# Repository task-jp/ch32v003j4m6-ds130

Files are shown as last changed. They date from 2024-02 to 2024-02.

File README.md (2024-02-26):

# Gathering CLOCK

Simple two LEDs clock that tells first 5mins in hours.

## Features
* pushing a button in 30 secs resets the clock

|Min|Green|Red|
|---|-----|---|
|0-5|On||
|5-10|Blink||
|10-55||On|
|55-60||Blink|

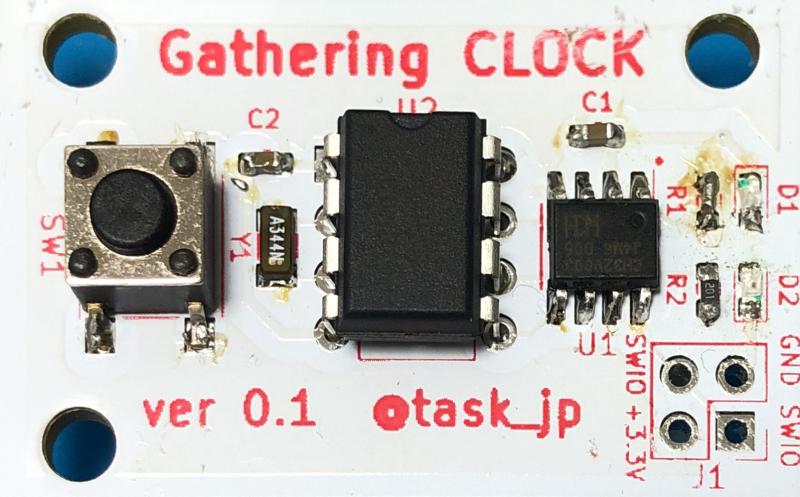
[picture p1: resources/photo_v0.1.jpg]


## Schematic and Layout

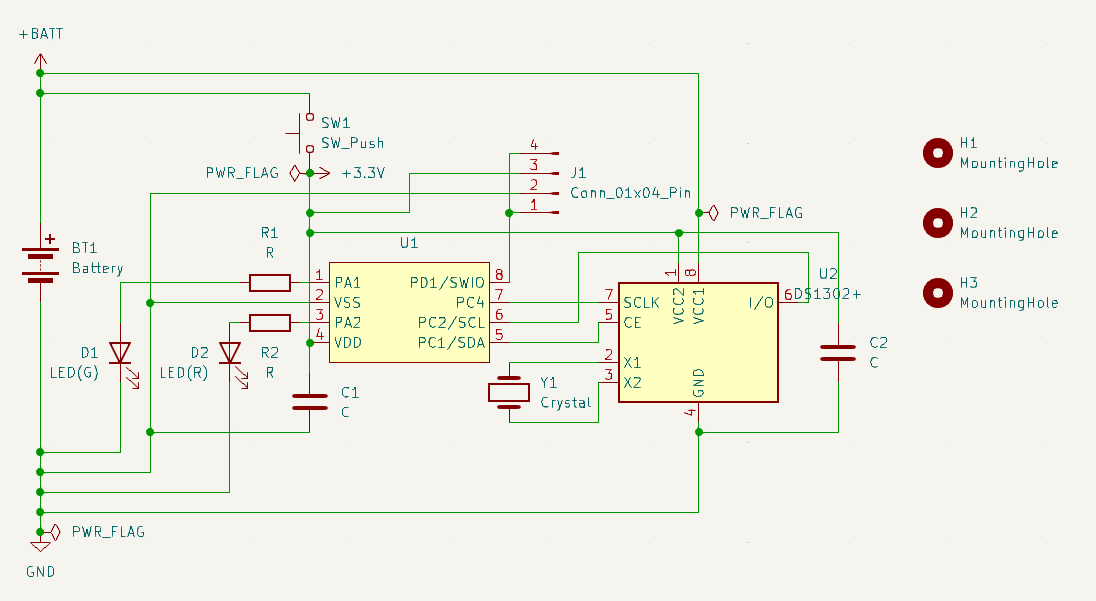
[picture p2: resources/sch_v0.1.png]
schmatic


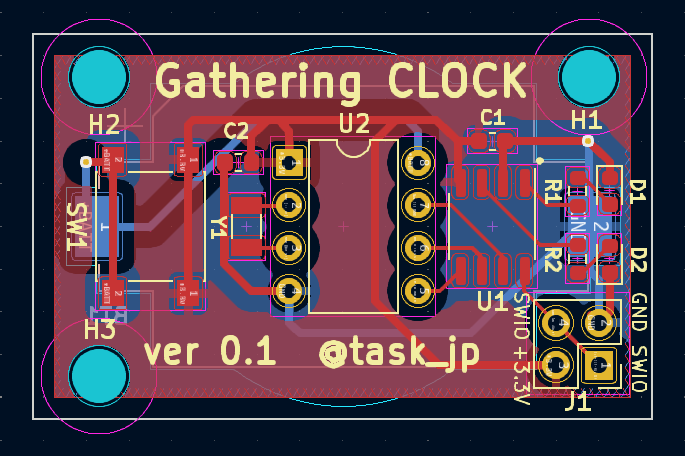
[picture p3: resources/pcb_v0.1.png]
layout


## Bill Of Materials
|Ref|Name|Qty|Description|Link|
|---|----|---|---|----|
|U1|CH32V003J4M6|1|Micro Controller|[https://akizukidenshi.com/catalog/g/g118062/](https://akizukidenshi.com/catalog/g/g118062/)|
|U2|DS1302+|1|RTC|[https://akizukidenshi.com/catalog/g/g113634/](https://akizukidenshi.com/catalog/g/g113634/)|
|BT1|Battery holder|1|CR2032|[https://akizukidenshi.com/catalog/g/g112908/](https://akizukidenshi.com/catalog/g/g112908/)|
|D1|LED|1|Green|[https://akizukidenshi.com/catalog/g/g106417/](https://akizukidenshi.com/catalog/g/g106417/)|
|D2|LED|1|Red|[https://akizukidenshi.com/catalog/g/g103978/](https://akizukidenshi.com/catalog/g/g103978/)|
|C1,C2|Capacitor|2|0.1uF|[https://akizukidenshi.com/catalog/g/g113374/](https://akizukidenshi.com/catalog/g/g113374/)|
|Y1|Crystal|1|32.768kHz|[https://akizukidenshi.com/catalog/g/g107195/](https://akizukidenshi.com/catalog/g/g107195/)|
|R1|Resistor 0|1|LED limit||
|R2|Resistor 200|1|LED limit|[https://akizukidenshi.com/catalog/g/g106201/](https://akizukidenshi.com/catalog/g/g106201/)|
|SW1|Push Switch|1||[https://akizukidenshi.com/catalog/g/g115969/](https://akizukidenshi.com/catalog/g/g115969/)|

## License
* MIT

## Author
* stasuku@gmail.com

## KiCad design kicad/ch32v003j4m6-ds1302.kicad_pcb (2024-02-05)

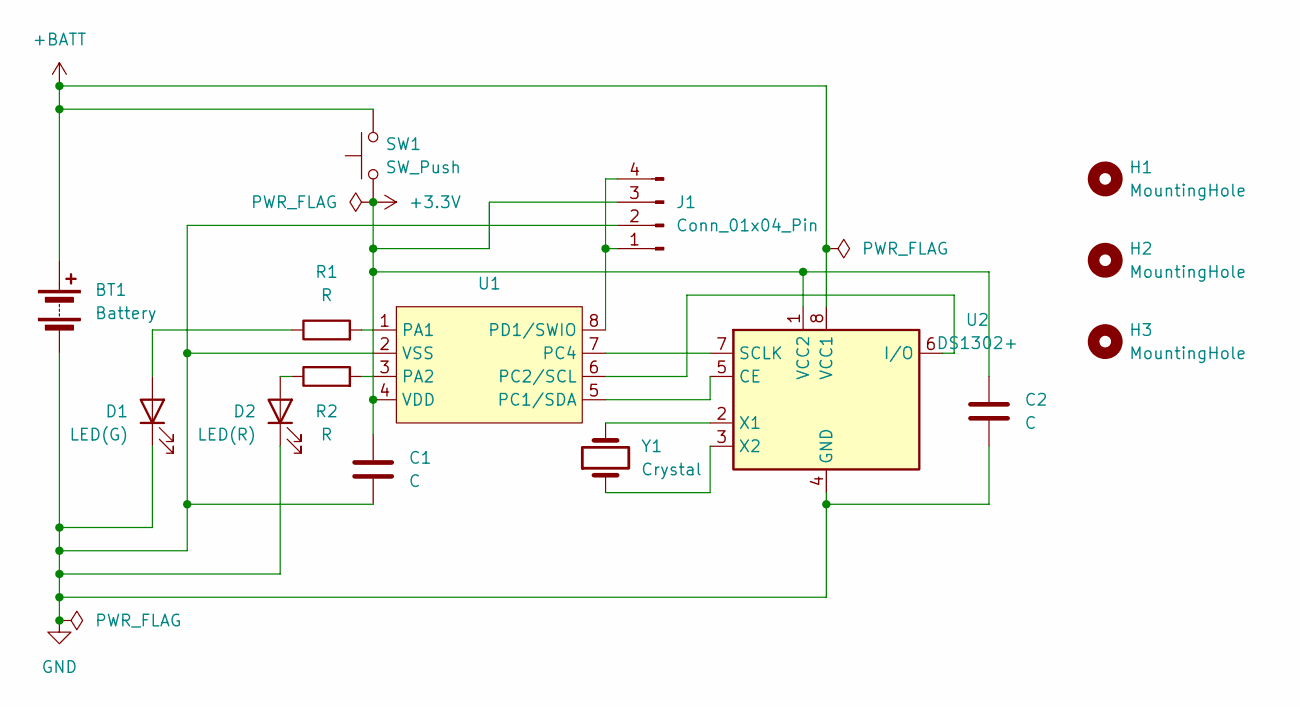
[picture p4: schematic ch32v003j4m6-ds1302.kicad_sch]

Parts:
BT1: Battery; BatteryHolder_Keystone_1060_1x2032
C1, C2: C; C_0603_1608Metric
D1: LED(G); LED_0603_1608Metric
D2: LED(R); LED_0603_1608Metric
H1, H2, H3: MountingHole; MountingHole_3.2mm_M3
J1: Conn_01x04_Pin; PinSocket_2x02_P2.54mm_Vertical
R1, R2: R; R_0603_1608Metric
SW1: SW_Push; SW_Push_1P1T_NO_6x6mm_H9.5mm
U1: SOP-8_3.9x4.9mm_P1.27mm
U2: DS1302+; DIP-8_W7.62mm
Y1: Crystal; Crystal_SMD_3215-2Pin_3.2x1.5mm

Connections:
+3.3V: C1.1, C2.1, J1.3, SW1.1, U1.4 (VDD), U2.1 (VCC2)
+BATT: BT1.1 (+), SW1.2, U2.8 (VCC1)
GND: BT1.2 (-), C1.2, C2.2, D1.1 (K), D2.1 (K), J1.2, U1.2 (VSS), U2.4 (GND)
unnamed: D1.2 (A), R1.1
unnamed: D2.2 (A), R2.1
unnamed: J1.1, J1.4, U1.8 (PD1/SWIO)
unnamed: R1.2, U1.1 (PA1)
unnamed: R2.2, U1.3 (PA2)
unnamed: U1.5 (PC1/SDA), U2.5 (CE)
unnamed: U1.6 (PC2/SCL), U2.6 (I/O)
unnamed: U1.7 (PC4), U2.7 (SCLK)
unnamed: U2.2 (X1), Y1.2
unnamed: U2.3 (X2), Y1.1

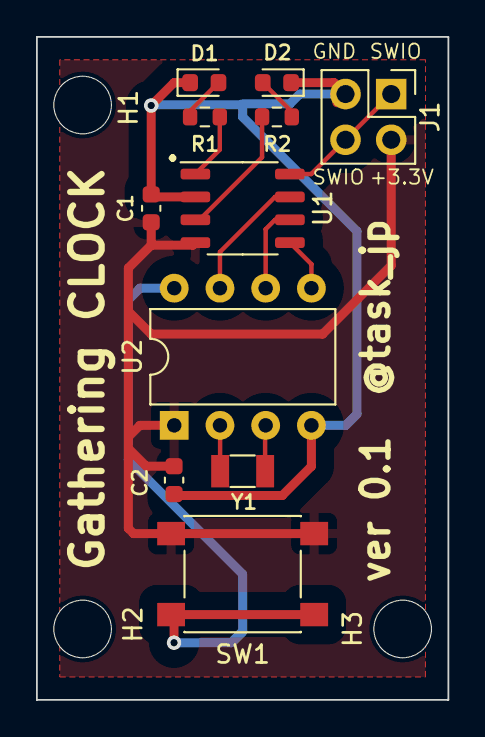
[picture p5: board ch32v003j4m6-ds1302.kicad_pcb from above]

Board: 2 copper layers, 22.9 x 36.8 mm, 15 parts (1 on the bottom side), 13 nets.

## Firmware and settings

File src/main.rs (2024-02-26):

#![no_std]
#![no_main]

use ch32v_rt::entry;
use ch32v00x_hal as hal;
use hal::gpio::PinState;
use hal::prelude::*;
use hal::pac::Peripherals;
use hal::println;
// use panic_halt as _;
use fugit::HertzU32 as Hertz;

use core::panic::PanicInfo;
#[panic_handler]
fn panic(_info: &PanicInfo) -> ! {
    println!("PANIC: {}", _info);
    loop {}
}

pub mod ds1302 {
    use ch32v00x_hal as hal;
    use hal::gpio::Output;
    use hal::gpio::PushPull;
    use hal::println;
    use embedded_hal::digital::v2::InputPin;
    use embedded_hal::digital::v2::OutputPin;

    pub trait Delay {
        fn delay_micro(&self, secs: u32);
        fn delay_nano(&self, secs: u32);
    }

    #[derive(Debug)]
    pub enum ReadWriteError {
        ChipSelectError,
        ClockError,
        ReadError,
        WriteError,
    }

    pub struct Ds1302<SCLK, const P: char, const N: u8, CE> {
        sclk: SCLK,
        io: Option<ch32v00x_hal::gpio::Pin<P, N, Output<PushPull>>>,
        ce: CE,
    }

    impl<SCLK, const P: char, const N: u8, CE> Ds1302<SCLK, P, N, CE> {
        pub fn new(sclk: SCLK, io: ch32v00x_hal::gpio::Pin<P, N, Output<PushPull>>, ce: CE) -> Self {
            Self {
                sclk,
                io: Some(io),
                ce,
            }
        }
    }

    fn encode_bcd(bcd: u8) -> u8 {
        bcd % 10 + ((bcd / 10) << 4)
    }

    fn decode_bcd(bcd: u8) -> u8 {
        (bcd & 0b0000_1111) + ((bcd & 0b1111_0000) >> 4) * 10
    }

    impl<SCLK, const P: char, const N: u8, CE> Ds1302<SCLK, P, N, CE>
    where 
        SCLK: OutputPin,
        CE: OutputPin,
    {
        pub fn is_running(&mut self, delay: &impl Delay) -> Result<bool, ReadWriteError> {
            let seconds = self.read(0x81, delay)?;
            Ok(seconds & 0b1000_0000 == 0b0000_0000)
        }

        pub fn get_seconds(&mut self, delay: &impl Delay) -> Result<u8, ReadWriteError> {
            let seconds = self.read(0x81, delay)?;
            Ok(decode_bcd(seconds & 0b0111_1111))
        }
        pub fn get_minutes(&mut self, delay: &impl Delay) -> Result<u8, ReadWriteError> {
            let minutes = self.read(0x83, delay)?;
            Ok(decode_bcd(minutes & 0b0111_1111))
        }
        pub fn get_hour(&mut self, delay: &impl Delay) -> Result<u8, ReadWriteError> {
            let hour = self.read(0x85, delay)?;
            let is_24h = hour & 0b1000_0000 == 0b0000_0000;
            let is_pm = hour & 0b0010_0000 == 0b0010_0000;
            if is_24h {
                Ok(decode_bcd(hour & 0b0011_1111))
            } else if is_pm {
                Ok(decode_bcd(hour & 0b0001_1111) + 12)
            } else {
                Ok(decode_bcd(hour & 0b0001_1111))
            }
        }

        pub fn get_date(&mut self, delay: &impl Delay) -> Result<u8, ReadWriteError> {
            let date = self.read(0x87, delay)?;
            Ok(decode_bcd(date & 0b0011_1111))
        }

        pub fn get_month(&mut self, delay: &impl Delay) -> Result<u8, ReadWriteError> {
            let month = self.read(0x89, delay)?;
            Ok(decode_bcd(month & 0b0001_1111))
        }

        pub fn get_day(&mut self, delay: &impl Delay) -> Result<u8, ReadWriteError> {
            let day = self.read(0x8B, delay)?;
            Ok(decode_bcd(day & 0b0000_0111))
        }

        pub fn get_year(&mut self, delay: &impl Delay) -> Result<u8, ReadWriteError> {
            let year = self.read(0x8D, delay)?;
            Ok(decode_bcd(year))
        }

        pub fn set_running(&mut self, is_running: bool, delay: &impl Delay) -> Result<(), ReadWriteError> {
            let mut seconds = self.read(0x81, delay)?;
            if is_running {
                seconds &= 0b0111_1111;
            } else {
                seconds |= 0b1000_0000;
            }
            self.write(0x80, seconds, delay)
        }

        pub fn set_seconds(&mut self, seconds: u8, delay: &impl Delay) -> Result<(), ReadWriteError> {
            let mut seconds = encode_bcd(seconds);
            if !self.is_running(delay)? {
                seconds |= 0b1000_0000;
            }
            self.write(0x80, seconds, delay)
        }

        pub fn set_minutes(&mut self, minutes: u8, delay: &impl Delay) -> Result<(), ReadWriteError> {
            let minutes = encode_bcd(minutes);
            self.write(0x82, minutes, delay)
        }

        pub fn set_hour(&mut self, hour: u8, delay: &impl Delay) -> Result<(), ReadWriteError> {
            let hour = encode_bcd(hour);
            self.write(0x84, hour, delay)
        }

        pub fn set_date(&mut self, date: u8, delay: &impl Delay) -> Result<(), ReadWriteError> {
            let date = encode_bcd(date);
            self.write(0x86, date, delay)
        }

        pub fn set_month(&mut self, month: u8, delay: &impl Delay) -> Result<(), ReadWriteError> {
            let month = encode_bcd(month);
            self.write(0x88, month, delay)
        }

        pub fn set_day(&mut self, day: u8, delay: &impl Delay) -> Result<(), ReadWriteError> {
            let day = encode_bcd(day);
            self.write(0x8A, day, delay)
        }

        pub fn set_year(&mut self, year: u8, delay: &impl Delay) -> Result<(), ReadWriteError> {
            let year = encode_bcd(year);
            self.write(0x8C, year, delay)
        }

        // https://akizukidenshi.com/download/ds/maxim/ds1302.pdf
        
        fn write(&mut self, addr: u8, data: u8, delay: &impl Delay) -> Result<(), ReadWriteError> {
            self.sclk.set_low().map_err(|_| ReadWriteError::ClockError)?;
            self.ce.set_high().map_err(|_| ReadWriteError::ChipSelectError)?;
            delay.delay_micro(4); // tCC = 4us for 2V
            self.write_byte(addr, delay)?;
            self.write_byte(data, delay)?;
            delay.delay_nano(300); // tCCH = 240ns for 2V
            self.ce.set_low().map_err(|_| ReadWriteError::ChipSelectError)?;
            delay.delay_micro(4); // tCWH = 4us for 2V
            Ok(())
        }

        fn read(&mut self, addr: u8, delay: &impl Delay) -> Result<u8, ReadWriteError> {
            self.sclk.set_low().map_err(|_| ReadWriteError::ClockError)?;
            self.ce.set_high().map_err(|_| ReadWriteError::ChipSelectError)?;
            delay.delay_micro(4); // tCC = 4us for 2V
            self.write_byte(addr, delay)?;
            let data = self.read_byte(delay)?;
            delay.delay_nano(300); // tCCH = 240ns for 2V
            self.ce.set_low().map_err(|_| ReadWriteError::ChipSelectError)?;
            delay.delay_micro(4); // tCWH = 4us for 2V
            // println!("read:  addr: {:02X}({:08b} <=> {:08b}), data: {:02X}({:08b})", addr, addr, command_byte, data, data);
            Ok(data)
        }

        // 1バイトを読み込む
        fn read_byte(&mut self, delay: &impl Delay) -> Result<u8, ReadWriteError> {
            let mut data = 0;
            self.sclk.set_low().map_err(|_| ReadWriteError::ClockError)?;
            let pin = self.io.take().unwrap().into_pull_up_input();
            for i in 0..8 {
                let bit = self.read_bit(&pin, delay)?;
                data |= match bit { true => 1, false => 0, } << i;
            }
            self.io = Some(pin.into_push_pull_output());
            Ok(data)
        }
        
        // 1ビットを読み込む
        fn read_bit(&mut self, pin: &impl InputPin, delay: &impl Delay) -> Result<bool, ReadWriteError> {
            delay.delay_nano(300); // tCCZ = 280ns for 2V
            self.sclk.set_high().map_err(|_| ReadWriteError::ClockError)?;
            let bit = pin.is_high().map_err(|_| ReadWriteError::ReadError)?;
            delay.delay_nano(2000); // tCH = 1000ns for 2V
            self.sclk.set_low().map_err(|_| ReadWriteError::ClockError)?;
            delay.delay_nano(1700); // tCL = 1000ns for 2V
            Ok(bit)
        }

        // 1バイトを書き込む
        fn write_byte(&mut self, byte: u8, delay: &impl Delay) -> Result<(), ReadWriteError> {
            self.sclk.set_low().map_err(|_| ReadWriteError::ClockError)?;
            let mut pin = self.io.take().unwrap();
            for i in 0..8 {
                self.write_bit(&mut pin, ((byte >> i) & 1) == 1, delay)?;
            }
            self.io = Some(pin);
            Ok(())
        }

        // 1ビットを書き込む
        fn write_bit(&mut self, pin: &mut impl OutputPin, bit: bool, delay: &impl Delay) -> Result<(), ReadWriteError> {
            let _ = pin.set_state(bit.into());
            delay.delay_nano(350); // tDC = 200ns for 2V
            self.sclk.set_high().map_err(|_| ReadWriteError::ClockError)?;
            delay.delay_nano(2000); // tCH = 1000ns for 2V
            self.sclk.set_low().map_err(|_| ReadWriteError::ClockError)?;
            delay.delay_nano(1700); // tCL = 1000ns for 2V
            Ok(())
        }
    }
}

struct Ch32Delay {
    sysclock: Hertz,
}

impl Ch32Delay {
    fn new(sysclock: Hertz) -> Self {
        Self {
            sysclock
        }
    }
    fn delay_milli(&self, secs: u32) {
        let cycles = self.sysclock.raw() / 1000 * secs / 2;
        unsafe {
            qingke::riscv::asm::delay(cycles);
        }
    }
}

impl ds1302::Delay for Ch32Delay {
    fn delay_micro(&self, secs: u32) {
        let cycles = self.sysclock.raw() / 1_000_000 * secs * 1000;
        unsafe {
            qingke::riscv::asm::delay(cycles);
        }
    }
    fn delay_nano(&self, secs: u32) {
        let cycles = self.sysclock.raw() as u64/ 1_000_000_000u64 * secs as u64 * 1000u64;
        unsafe {
            qingke::riscv::asm::delay(cycles as u32);
        }
    }
}

#[entry]
fn main() -> ! {
    hal::debug::SDIPrint::enable();

    let pac = Peripherals::take().unwrap();

    let mut rcc = pac.RCC.constrain();
    let clocks = rcc.config.freeze();
    let delay = Ch32Delay::new(clocks.sysclk());

    let gpioa = pac.GPIOA.split(&mut rcc);
    let gpioc = pac.GPIOC.split(&mut rcc);

    let mut green = gpioa.pa1.into_push_pull_output();
    let mut red = gpioa.pa2.into_push_pull_output();

    let sclk = gpioc.pc4.into_push_pull_output();
    let io = gpioc.pc2.into_push_pull_output();
    let ce = gpioc.pc1.into_push_pull_output_in_state(PinState::Low);
    let mut ds1302 = ds1302::Ds1302::new(sclk, io, ce);

    ds1302.set_running(true, &delay).unwrap();
    
    let mut pressed = 0;
    let mut last_seconds = 0xffu8;

    green.set_high();
    red.set_high();
    
    loop {
        delay.delay_milli(10);
        let seconds = ds1302.get_seconds(&delay).unwrap();
        if seconds == last_seconds {
            continue;
        }
        last_seconds = seconds;

        if pressed == 30 {
            ds1302.set_minutes(0, &delay).unwrap();
            ds1302.set_seconds(0, &delay).unwrap();
            last_seconds = 0xffu8;
            green.set_high();
            red.set_high();
            continue;
        } else {
            pressed += 1;
        }

        let minutes = ds1302.get_minutes(&delay).unwrap();

        match minutes {
            55..=60 => {
                // 待ち合わせ時間直前は赤を点滅
                green.set_low();
                red.set_state((seconds % 2 == 0).into());
            },
            0..=4 => {
                // 待ち合わせ時間内は緑を点灯
                green.set_high();
                red.set_low();
            },
            5..=10 => {
                // 待ち合わせ時間が過ぎたら緑を点灯
                green.set_state((seconds % 2 == 0).into());
                red.set_low();
            },
            _ => {
                // それ以外の場合は赤を点灯
                green.set_low();
                red.set_high();
            }
        }
        // println!("{:02}:{:02}", minutes, seconds);
        delay.delay_milli(900);
    }
}

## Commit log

2024-01-30 remove reversing when writing
    [main.rs]
2024-01-31 Add kicad files
    [ch32v004jm6-ds1302.kicad_pcb, ch32v004jm6-ds1302.kicad_sch]
2024-01-31 Fix hour in 24 style issue
    [main.rs]
2024-02-02 Update CAD data
    [ch32v004jm6-ds1302.kicad_pcb, ch32v004jm6-ds1302.kicad_sch]
2024-02-02 Add .gitignore for kicad
2024-02-02 Fix typo
    [ch32v003j4m6-ds1302.kicad_pcb, ch32v003j4m6-ds1302.kicad_sch]
2024-02-02 Fix silk font height and assign +BATT to Power net class
    [ch32v003j4m6-ds1302.kicad_pcb]
2024-02-02 Add a resistor for LED(G)
    [ch32v003j4m6-ds1302.kicad_pcb, ch32v003j4m6-ds1302.kicad_sch]
2024-02-02 Minimize size
    [ch32v003j4m6-ds1302.kicad_pcb]
2024-02-05 Fix mouting hole
    [ch32v003j4m6-ds1302.kicad_pcb, ch32v003j4m6-ds1302.kicad_sch]
2024-02-05 Add title to sch
    [ch32v003j4m6-ds1302.kicad_sch]
2024-02-26 Run on a real device
2024-02-26 Wait 30 secs to reset
    [main.rs]
2024-02-26 Rotate pcb image
2024-02-26 Turn on two LEDs at first
